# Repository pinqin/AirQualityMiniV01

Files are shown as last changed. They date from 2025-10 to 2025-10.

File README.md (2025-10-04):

# AirQualityMiniV01

This repository contains the design files for a printed circuit board (PCB) featuring an ESP32-C3 microcontroller and a BME688 environmental sensor.
Included are schematics, PCB layout files, and the bill of materials (BOM).
Key Components (BOM excerpt)

U1: BME688 (environmental sensor)

U2: ESP32-C3 (WiFi/Bluetooth SoC)

U3: USB-C connector – DX07S016JA1R1500

U4: Antenna – ANT3216LL00R2400A

U5: Voltage regulator – TLV62568DBVR









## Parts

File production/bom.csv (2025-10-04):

Designator | Footprint | Quantity | Value | LCSC Part #
C1, C21, C5, C6 | 0603 | 4 | 100nF | CC0603KRX7R9BB104
C10 | 0805 | 1 | 4.7µF | GRM21BR71A475KA73L
C11 | 0805 | 1 | 10µF | GRM21BR71A106KE51L
C2, C20, C7 | 0603 | 3 | 10µF | GRM188R61A106KE69D
C23 | 0603 | 1 | 6.8pF | CC0402CRNPO9BN6R8
C3, C4 | 0603 | 2 | C
J1 | 1051620001 | 1 | ~ | 1051620001
L2 | 1008 | 1 | 2µ2 | C315713
R1, R19, R3, R4, R9 | 0603 | 5 | 10K | RC0603FR-0710KL
R10 | 0402 | 1 | 450K | FRC0402F4503TS
R18 | 0603 | 1 | 100K 1% | RC0603FR-07100KL
R2 | 0603 | 1 | 0R | RC0603JR-070RL
R48, R49 | 0603 | 2 | 5K1 | RC0603FR-075K1L
U1 | LGA-8_L3.0-W3.0-P0.80_BME688 | 1 | BME688_C3664478 | C3664478
U2 | QFN-32-1EP_5x5mm_P0.5mm_EP3.7x3.7mm | 1 | ESP32-C3 | ESP32-C3
U3 | USB-C-SMD_DX07S016JA1R1500 | 1 | DX07S016JA1R1500_C3197885 | C3197885
U4 | ANT-SMD_L3.2-W1.6 | 1 | ANT3216LL00R2400A | C293767
U5 | SOT-23-5 | 1 | TLV62568DBV | TLV62568DBVR

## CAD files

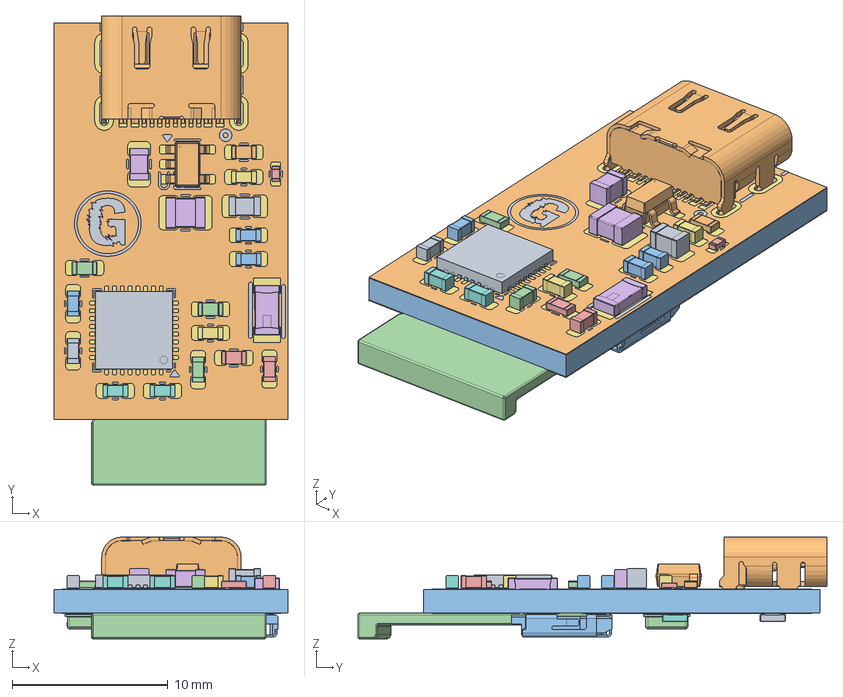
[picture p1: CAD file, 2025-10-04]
mech/assy.FCStd
15.0 x 30.1 x 6.53 mm
C_0805_2012Metric
R_0603_1608Metric
C_0603_1608Metric
C_0603_1608Metric001
C_0603_1608Metric002
L_1008_2520Metric
C_0603_1608Metric003
C_0603_1608Metric004
QFN-32-1EP_5x5mm_P0.5mm_EP3.7x3.7mm
USB-C-SMD_DX07S016JA1R1500
C_0603_1608Metric005
R_0603_1608Metric001
R_0603_1608Metric002
ANT-SMD_L3.2-W1.6-H1.3
C_0603_1608Metric006
C_0603_1608Metric007
C_0603_1608Metric008
SOT-23-5
C_0603_1608Metric009
R_0603_1608Metric003
R_0402_1005Metric
C_0805_2012Metric001
R_0603_1608Metric004
R_0603_1608Metric005
R_0603_1608Metric006
R_0603_1608Metric007
LGA-8_L3.0-W3.0-P0.80_BME688
R_0603_1608Metric008
AirQualityMiniV01_copper
AirQualityMiniV01_pad
AirQualityMiniV01_via
AirQualityMiniV01_silkscreen
AirQualityMiniV01_soldermask
AirQualityMiniV01_PCB
MicroSD

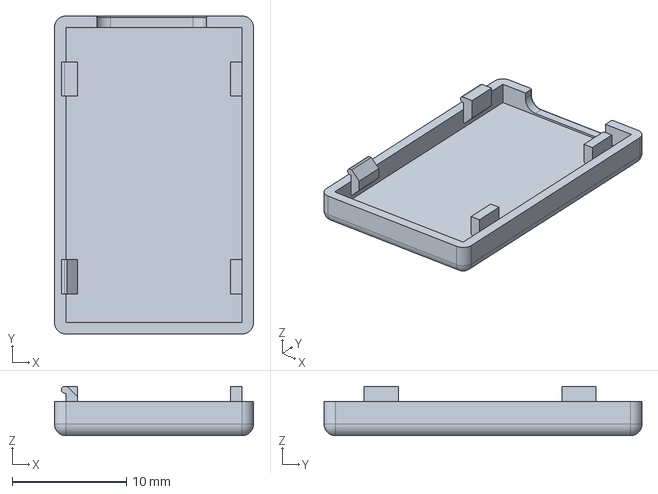
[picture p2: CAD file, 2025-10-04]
mech/oberteil.FCStd
17.4 x 27.8 x 4.30 mm

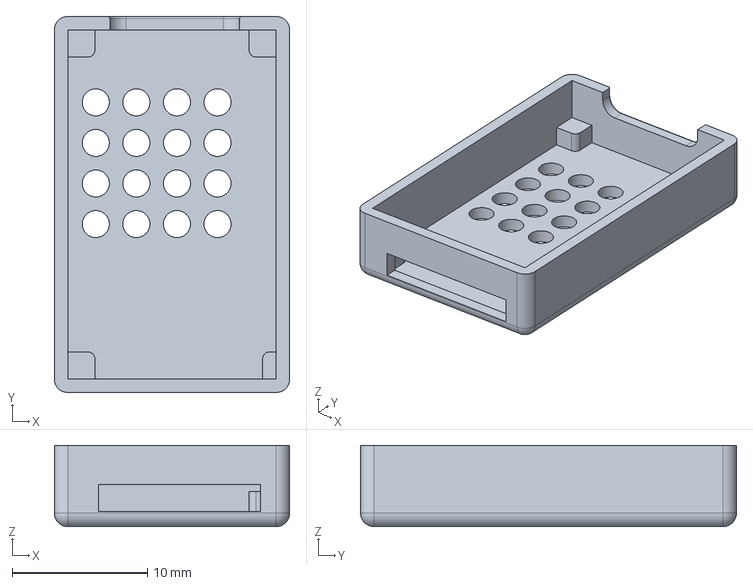
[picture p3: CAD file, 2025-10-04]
mech/unterteil.FCStd
17.4 x 27.8 x 6.00 mm

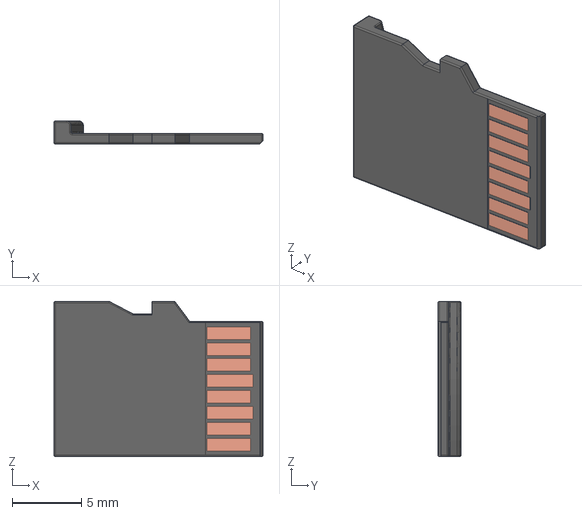
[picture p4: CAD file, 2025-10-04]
mech/MicroSD.stp
15.1 x 1.65 x 11.2 mm

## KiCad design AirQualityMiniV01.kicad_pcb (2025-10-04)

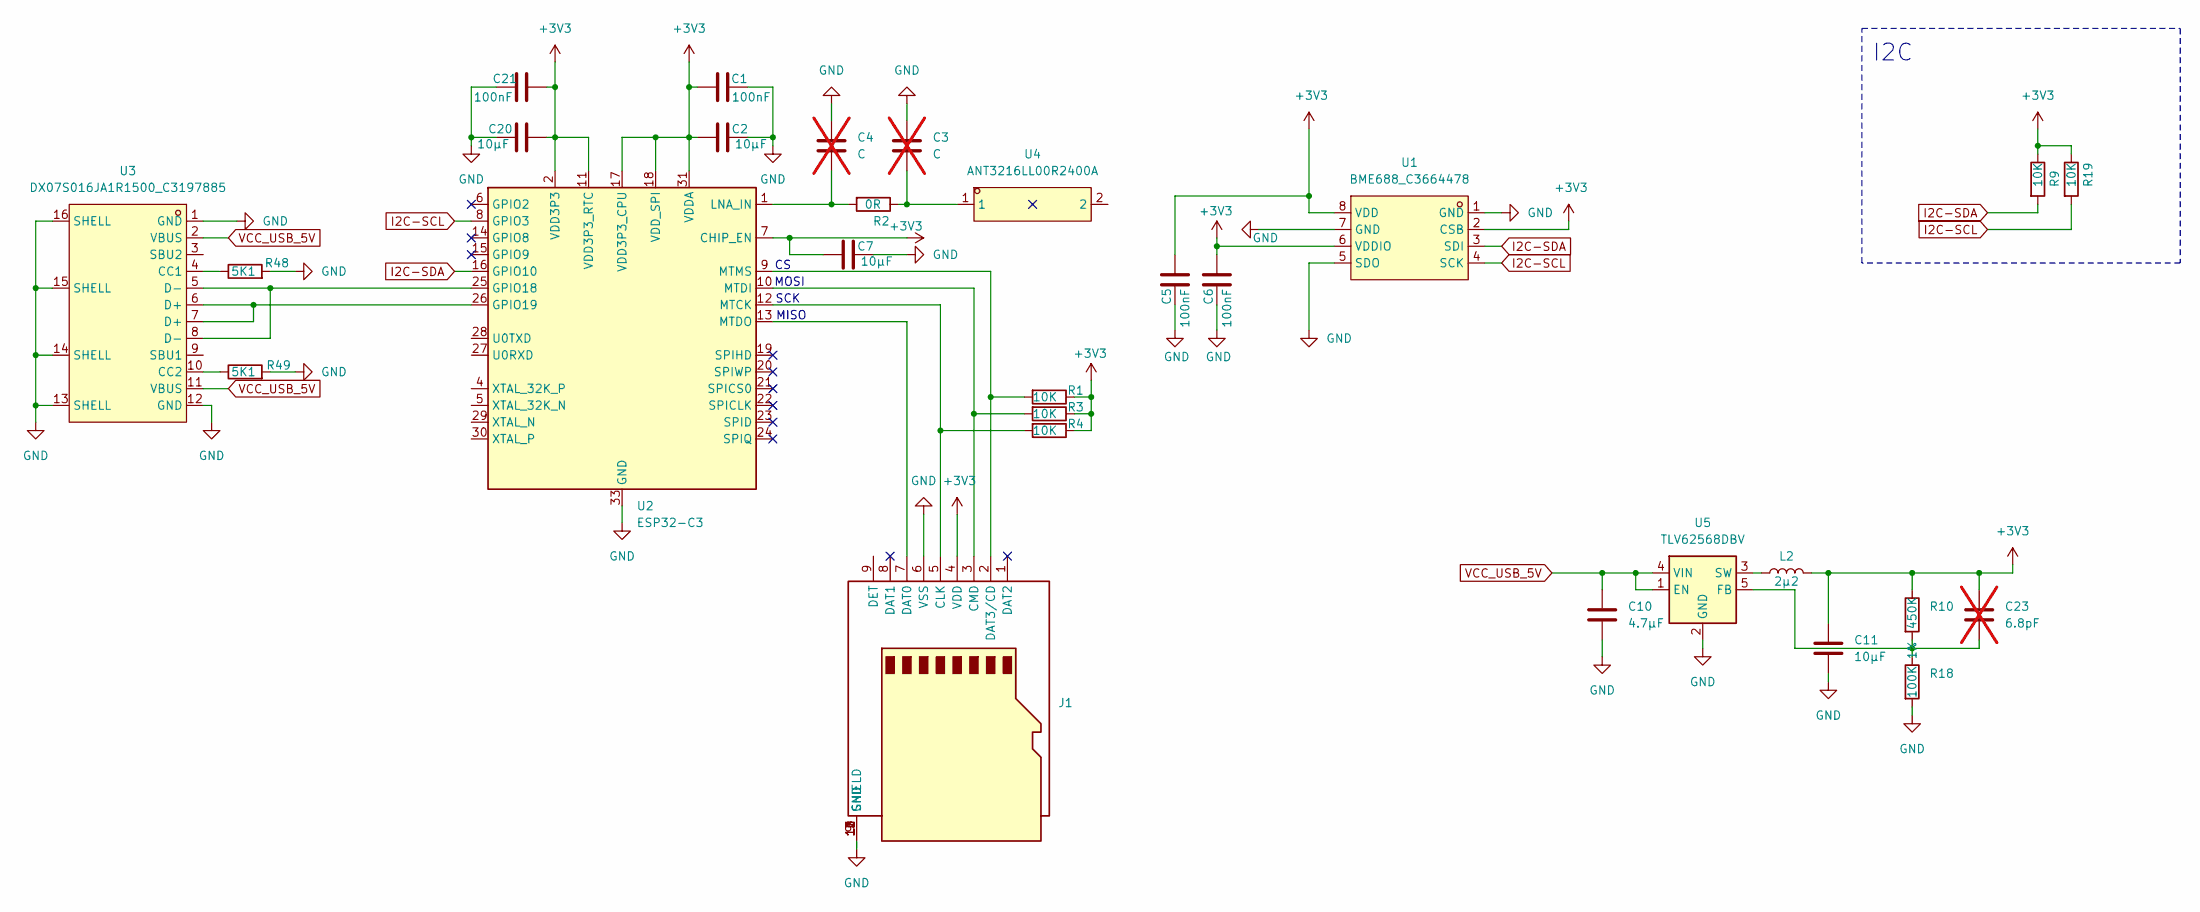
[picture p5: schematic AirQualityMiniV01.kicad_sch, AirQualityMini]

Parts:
C1, C5, C6, C21: 100nF; C_0603_1608Metric; MPN CC0603KRX7R9BB104; LCSC Partnumber C14663
C2, C7, C20: 10µF; C_0603_1608Metric; MPN GRM188R61A106KE69D; LCSC Partnumber C77044
C3, C4: C; C_0603_1608Metric; not fitted
C10: 4.7µF; C_0805_2012Metric; MPN GRM21BR71A475KA73L; LCSC Partnumber C86039
C11: 10µF; C_0805_2012Metric; MPN GRM21BR71A106KE51L; LCSC Partnumber C86038
C23: 6.8pF; C_0603_1608Metric; MPN CC0402CRNPO9BN6R8; LCSC Partnumber C189470; not fitted
J1: 1051620001; MPN 1051620001; LCSC Partnumber C3177046
L2: 2µ2; L_1008_2520Metric; MPN WIP252010P-2R2ML; LCSC C315713
R1, R3, R4, R9, R19: 10K; R_0603_1608Metric; MPN RC0603FR-0710KL; LCSC Partnumber C98220
R2: 0R; R_0603_1608Metric; MPN RC0603JR-070RL; LCSC Partnumber C95177
R10: 450K; R_0402_1005Metric; MPN FRC0402F4503TS; LCSC Partnumber C5159688
R18: 100K 1%; R_0603_1608Metric; MPN RC0603FR-07100KL; LCSC Partnumber C14675
R48, R49: 5K1; R_0603_1608Metric; MPN RC0603FR-075K1L; LCSC Partnumber C105580
U1: BME688_C3664478; LGA-8_L3.0-W3.0-P0.80_BME688; MPN BME688; LCSC Part C3664478
U2: ESP32-C3; QFN-32-1EP_5x5mm_P0.5mm_EP3.7x3.7mm; MPN ESP32-C3
U3: DX07S016JA1R1500_C3197885; USB-C-SMD_DX07S016JA1R1500; LCSC Part C3197885
U4: ANT3216LL00R2400A; ANT-SMD_L3.2-W1.6; MPN ANT3216LL00R2400A; LCSC Part C293767
U5: TLV62568DBV; SOT-23-5; MPN TLV62568DBVR; LCSC Partnumber C163219

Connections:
+3V3: C1.2, C2.2, C5.2, C6.2, C7.2, C11.1, C20.2, C21.2, C23.1, J1.4 (VDD), L2.2, R1.1, R3.1, R4.1, R9.1, R10.1, R19.1, U1.2 (CSB), U1.6 (VDDIO), U1.8 (VDD), U2.2 (VDD3P3), U2.3 (VDD3P3), U2.7 (CHIP_EN), U2.11 (VDD3P3_RTC), U2.17 (VDD3P3_CPU), U2.18 (VDD_SPI), U2.31 (VDDA), U2.32 (VDDA)
GND: C1.1, C2.1, C3.1, C4.1, C5.1, C6.1, C7.1, C10.2, C11.2, C20.1, C21.1, J1.6 (VSS), J1.9 (SHIELD), J1.10 (GND), J1.11 (GND), J1.12 (GND), J1.13 (GND), R18.2, R48.2, R49.2, U1.1 (GND), U1.5 (SDO), U1.7 (GND), U2.33 (GND), U3.1 (GND), U3.12 (GND), U3.13 (SHELL), U3.14 (SHELL), U3.15 (SHELL), U3.16 (SHELL), U5.2 (GND)
I2C-SCL: R19.2, U1.4 (SCK), U2.8 (GPIO3)
I2C-SDA: R9.2, U1.3 (SDI), U2.16 (GPIO10)
unnamed: C3.2, R2.1, U4.1
unnamed: J1.5 (CLK), R4.2, U2.12 (MTCK)
unnamed: J1.3 (CMD), R3.2, U2.10 (MTDI)
unnamed: J1.7 (DAT0), U2.13 (MTDO)
unnamed: J1.2 (DAT3/CD), R1.2, U2.9 (MTMS)
unnamed: U2.25 (GPIO18), U3.5 (D-), U3.8 (D-)
unnamed: U2.26 (GPIO19), U3.6 (D+), U3.7 (D+)
unnamed: C4.2, R2.2, U2.1 (LNA_IN)
unnamed: R48.1, U3.4 (CC1)
unnamed: R49.1, U3.10 (CC2)
unnamed: C23.2, R10.2, R18.1, U5.5 (FB)
unnamed: L2.1, U5.3 (SW)
VCC_USB_5V: C10.1, U3.2 (VBUS), U3.11 (VBUS), U5.1 (EN), U5.4 (VIN)

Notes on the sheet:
MOSI
MISO
SCK
I2C

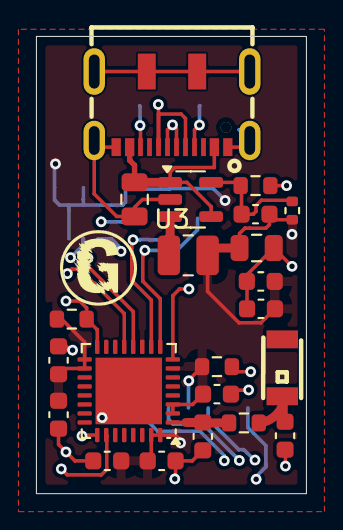
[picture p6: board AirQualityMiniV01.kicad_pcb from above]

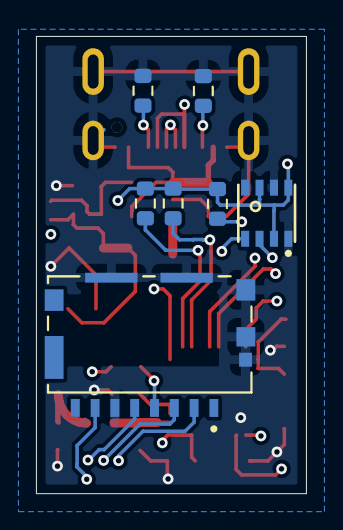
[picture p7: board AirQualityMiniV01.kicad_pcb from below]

Board: 4 copper layers, 15.0 x 25.4 mm, 29 parts (7 on the bottom side), 17 nets.
